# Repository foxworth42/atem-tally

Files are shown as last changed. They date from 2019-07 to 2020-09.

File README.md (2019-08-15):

# atem-tally
Yet another Arduino based ATEM tally light system.  This system is self-contained and talks to the ATEM directly.  The on camera lights are neo pixels driven over RS485 to allow for long cable runs.  The cabling between the cameras is done using ethernet cables for simplicity of wiring so we can send power + data to the remote lights.  The tally controller will also have a 20x4 LCD display for showing system status.  An XBee can also be added for supporting wireless remote tally lights.

# Still a work-in-progress

Everything here is still a work in process at the moment.  

Arduino code makes use of [Skaarhoj's Open Engineering arduino libraries](https://github.com/kasperskaarhoj/SKAARHOJ-Open-Engineering/tree/master/ArduinoLibs) for communicating with the Black Magic ATEM video switcher

Why roll something myself?  Cost, and it's an excuse to learn some C and do some PCB design.

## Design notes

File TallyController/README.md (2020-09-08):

Arduino based tally controller using the Arduino Mega w/ Ethernet.

Configuration of the tally controller is done via serial connection.  To configure send the following:

|Setting|Command|Note|
|---|---|---|
|Controller's IP|`Ix.x.x.x`|Replace x's with the controller's IP address|
|Controller's Netmask|`Nx.x.x.x`|Replace the x's with the controller's netmask|
|ATEM's IP|`Ax.x.x.x`|Replace the x's with the ATEM's IP address|
|Remote Camera #|`Rx`|Replace the x's with the camera # the wireless tally light is attached to|

Sample build of ATEM tally controller built in a parts organizer for portability for on-location use at conventions.

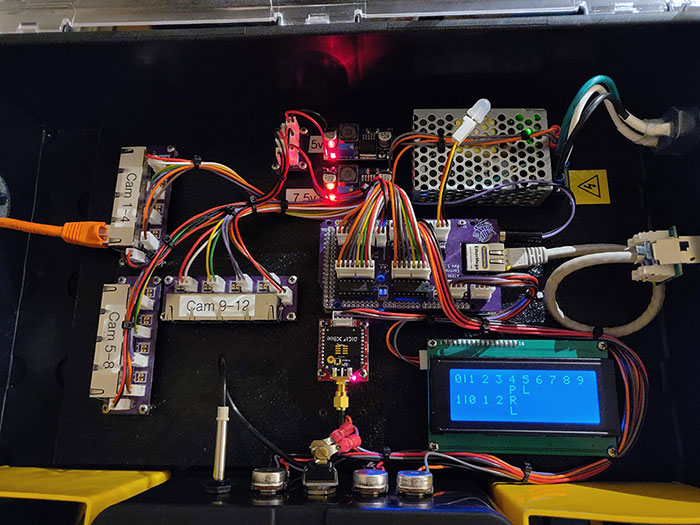
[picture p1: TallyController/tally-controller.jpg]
ATEM Tally Controller


# BOM:

## Controller Board:

For `tally-controller-shield-smd.brd`

|Component|Quantity|Notes|Link|
|---|---|---|---|
|Controller Shield PCB|1|Can have board fabbed anywhere.|[Link](https://oshpark.com/shared_projects/vglxha97)|
|Freetronics EtherMEGA|1|Arduino Mega + Ethernet bundle.  I do not recommend using the Mega ETH from RobotDyn.|[Link](https://www.freetronics.com.au/products/ethermega-arduino-mega-2560-compatible-with-onboard-ethernet)|
|SN75174N RS485 Quad Line Driver|3| |[Link](https://www.mouser.com/ProductDetail/595-SN75174N)|
|LM2596 DC/DC buck converters|2|I used 1 for the main 5v for the project, and the other just for powering the Ethermega|[Link](https://www.amazon.com/dp/B06XZ1DKF2/ref=cm_sw_em_r_mt_dp_U_vQXREb0CJX45Z)|
|Molex 22-23-2021 2-pin header|4| |[Link](https://www.mouser.com/ProductDetail/538-22-23-2021)|
|Molex 22-23-2031 3-pin header|3| |[Link](https://www.mouser.com/ProductDetail/538-22-23-2031)|
|Molex 22-23-2041 4-pin header|2| |[Link](https://www.mouser.com/ProductDetail/538-22-23-2041)|
|Molex 22-23-2081 8-pin header|3| |[Link](https://www.mouser.com/ProductDetail/538-22-23-2081)|
|470ohm 0805 SMD resistor|1| | |
|10kohm 0805 SMD resistor|1| | |
|4.7kohm 0805 SMD resistor|1| | |
|120ohm 0805 SMD resistor|12| | |
|0.1uf 0805 SMD ceramic capacitor|3| | |
|10kohm potentiometer|2| |[Link](https://www.mouser.com/ProductDetail/858-P231-QC15BR10K)|
|1kohm potentiometer|1| | |
|Potentiometer knob|3| |[Red](https://www.mouser.com/ProductDetail/450-3021), [Green](https://www.mouser.com/ProductDetail/450-3024), [Blue](https://www.mouser.com/ProductDetail/450-3023), [Yellow](https://www.mouser.com/ProductDetail/450-3022)
|SPST Toggle Swithch|1| | |
|Mean Well RS-25-12 Power Supply|1| |[Link](https://www.mouser.com/ProductDetail/709-RS25-12)|
|Sparkfun XBee regulated breakout|1|Optional|[Link](https://www.mouser.com/ProductDetail/474-WRL-11373)|
|XBee Pro Transciever|1|Optional|[Link](https://www.mouser.com/ProductDetail/888-XB3-24Z8ST)|
|Dome atenna for Xbee|1|Optional|[Link](https://www.mouser.com/ProductDetail/712-ANT-DB1-WRT-RPS)|
|20x4 LCD i2c Display|1|Can be had cheap off ebay| |

## Camera output board:

For `RJ45 4ch Outout.brd`

Quantities noted here are for each output board.  Multiply as needed for multiple boards.

|Component|Quantity|Notes|Link|
|---|---|---|---|
|Output PCB|1|Oshpark minimum order is 3|[Link](https://oshpark.com/shared_projects/SH81yZph)|
|Amphenol RJHSE-5380-04|1|4-port RJ45 module|[Link](https://www.mouser.com/ProductDetail/523-RJHSE-5380-04)|
|Molex 22-23-2021 2-pin header|4|Only needed for CAM#DATA1 headers.  CAM#DATA2 is unused currently.|[Link](https://www.mouser.com/ProductDetail/538-22-23-2021)|

## Power distribution

For `Output Power Distro.brd`

Small board for distributing the 5v power to the controller shield, camera output boards

|Component|Quantity|Notes|Link|
|---|---|---|---|
|Power Distro PCB|1|Oshpark minimum order is 3|[Link](https://oshpark.com/shared_projects/CbdMb8Fg)|
|Molex 22-23-2021 2-pin header|6|Only needed for CAM#DATA1 headers.  CAM#DATA2 is unused currently.|[Link](https://www.mouser.com/ProductDetail/538-22-23-2021)|

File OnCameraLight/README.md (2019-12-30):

RS485 receiver to Neopixel adapter for on-camera light.

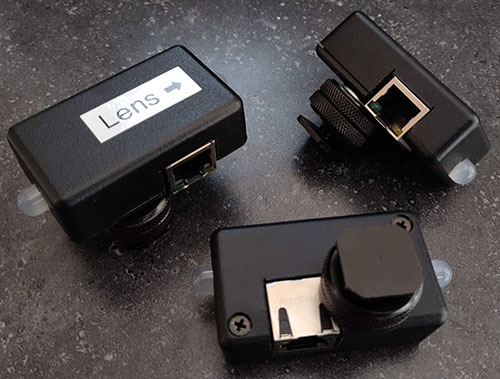
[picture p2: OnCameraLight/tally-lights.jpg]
On Camera Tally Light


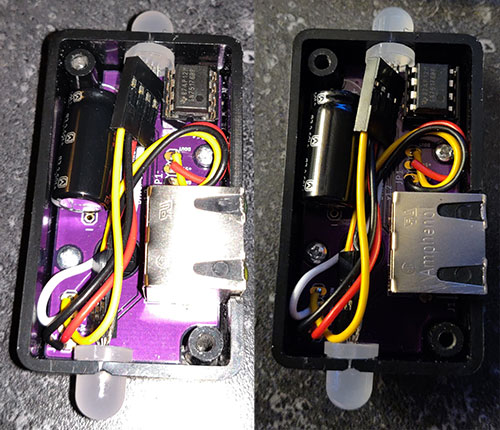
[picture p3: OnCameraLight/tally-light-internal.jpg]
On Camera Tally Light Internals


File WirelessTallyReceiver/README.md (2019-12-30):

XBee + Arduino Mini Pro based tally receiver.  Uses the same Neopixel LEDs as the wired lights, but wireless.

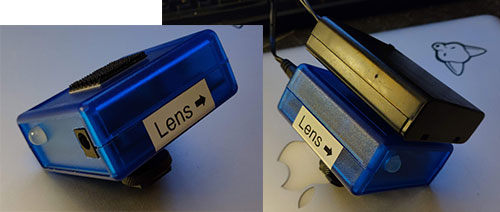
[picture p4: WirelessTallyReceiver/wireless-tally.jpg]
Wireless Tally Light


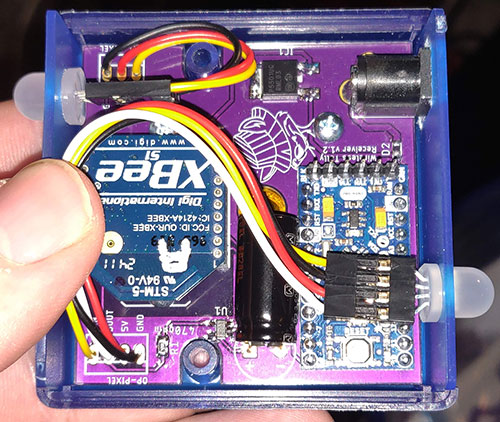
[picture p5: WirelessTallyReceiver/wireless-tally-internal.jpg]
Wireless Tally Light Internal


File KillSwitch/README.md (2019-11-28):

#Arduino based ATEM kill switch using Uno + Ethernet

This is for having an emergency kill switch for an ATEM that will dump
both the program and preview source to a pre-defined source if the button
is hit.  The reason it sets both program and preview is so that there 
needs to be manual intervention to bring the feed back online.

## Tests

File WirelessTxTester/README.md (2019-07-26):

Small sketch that can be used to test the wireless receiver, just cycles through the light options.

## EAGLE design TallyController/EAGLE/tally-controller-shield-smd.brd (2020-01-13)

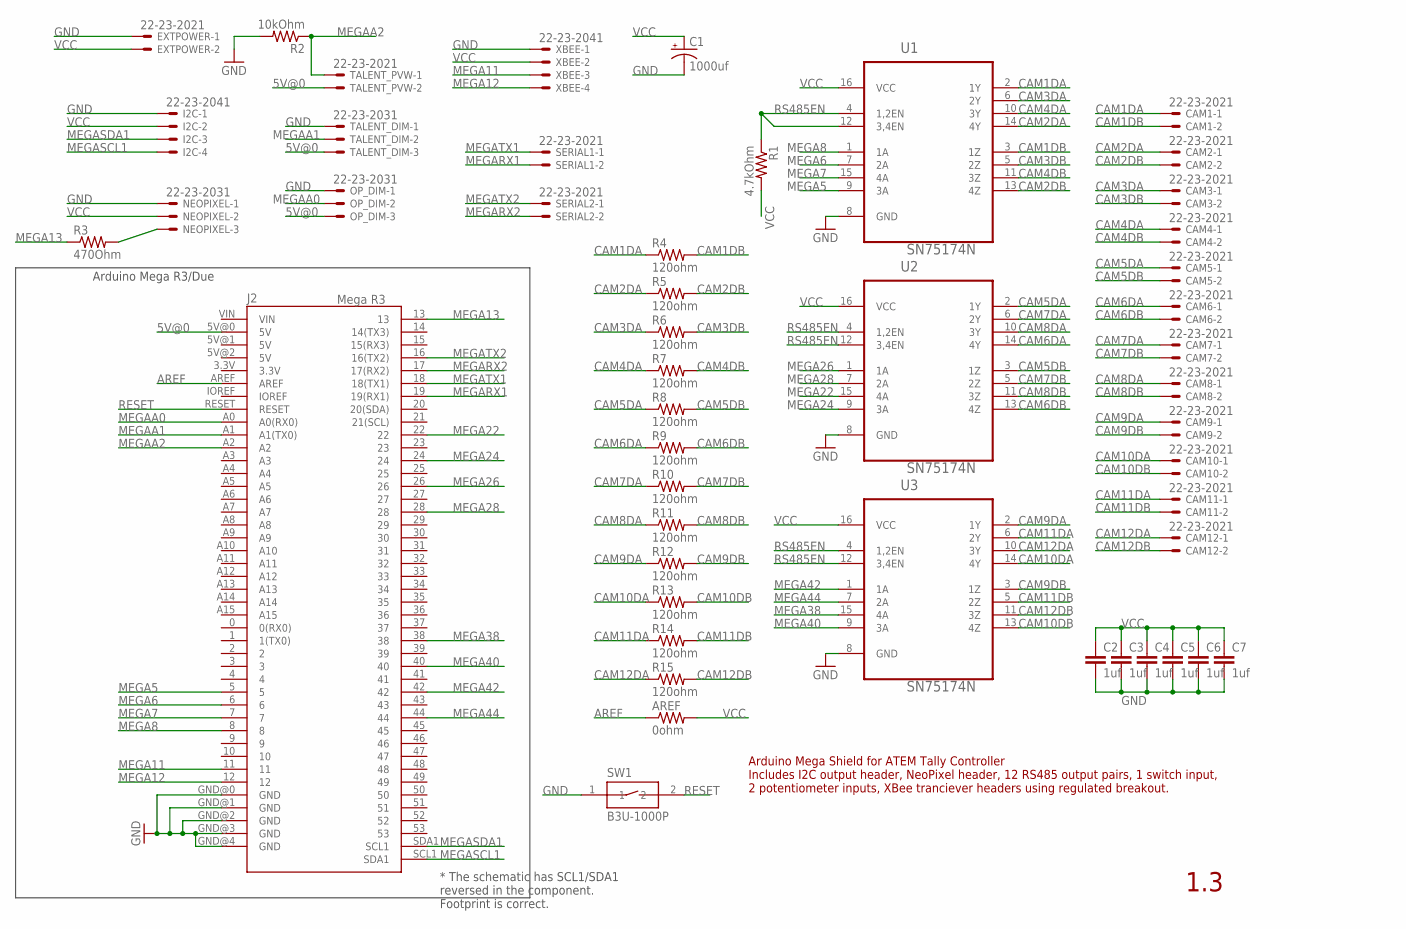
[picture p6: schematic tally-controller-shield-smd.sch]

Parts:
AREF: 0ohm; 0204V
C1: 1000uf; CPOL-RADIAL-5MM-10MM
C2, C3, C4, C5, C6, C7: 1uf; RESC0805_N
CAM1, CAM2, CAM3, CAM4, CAM5, CAM6, CAM7, CAM8, CAM9, CAM10, CAM11, CAM12: 22-23-2021
EXTPOWER: 22-23-2021
I2C: 22-23-2041
J2: Mega R3; ARDUINO_MEGA
NEOPIXEL: 22-23-2031
OP_DIM: 22-23-2031
R1: 4.7kOhm; R0805
R2: 10kOhm; R0805
R3: 470Ohm; R0805
R4, R5, R6, R7, R8, R9, R10, R11, R12, R13, R14, R15: 120ohm; R0805
SERIAL1, SERIAL2: 22-23-2021
SW1: B3U-1000P
TALENT_DIM: 22-23-2031
TALENT_PVW: 22-23-2021
U1, U2, U3: SN75174N; DIP254P762X508-16
XBEE: 22-23-2041

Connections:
5V@0: J2.5V@0 (5V), OP_DIM.3, TALENT_DIM.3, TALENT_PVW.2
AREF: AREF.1, J2.AREF
CAM1DA: CAM1.1, R4.1, U1.2 (1Y)
CAM1DB: CAM1.2, R4.2, U1.3 (1Z)
CAM2DA: CAM2.1, R5.1, U1.14 (4Y)
CAM2DB: CAM2.2, R5.2, U1.13 (4Z)
CAM3DA: CAM3.1, R6.1, U1.6 (2Y)
CAM3DB: CAM3.2, R6.2, U1.5 (2Z)
CAM4DA: CAM4.1, R7.1, U1.10 (3Y)
CAM4DB: CAM4.2, R7.2, U1.11 (3Z)
CAM5DA: CAM5.1, R8.1, U2.2 (1Y)
CAM5DB: CAM5.2, R8.2, U2.3 (1Z)
CAM6DA: CAM6.1, R9.1, U2.14 (4Y)
CAM6DB: CAM6.2, R9.2, U2.13 (4Z)
CAM7DA: CAM7.1, R10.1, U2.6 (2Y)
CAM7DB: CAM7.2, R10.2, U2.5 (2Z)
CAM8DA: CAM8.1, R11.1, U2.10 (3Y)
CAM8DB: CAM8.2, R11.2, U2.11 (3Z)
CAM9DA: CAM9.1, R12.1, U3.2 (1Y)
CAM9DB: CAM9.2, R12.2, U3.3 (1Z)
CAM10DA: CAM10.1, R13.1, U3.14 (4Y)
CAM10DB: CAM10.2, R13.2, U3.13 (4Z)
CAM11DA: CAM11.1, R14.1, U3.6 (2Y)
CAM11DB: CAM11.2, R14.2, U3.5 (2Z)
CAM12DA: CAM12.1, R15.1, U3.10 (3Y)
CAM12DB: CAM12.2, R15.2, U3.11 (3Z)
GND: C1.-, C2.2, C3.2, C4.2, C5.2, C6.2, C7.2, EXTPOWER.1, I2C.1, J2.GND@0 (GND), J2.GND@1 (GND), J2.GND@2 (GND), J2.GND@3 (GND), J2.GND@4 (GND), NEOPIXEL.1, OP_DIM.1, R2.2, SW1.1, TALENT_DIM.1, U1.8 (GND), U2.8 (GND), U3.8 (GND), XBEE.1
MEGA5: J2.5, U1.9 (3A)
MEGA6: J2.6, U1.7 (2A)
MEGA7: J2.7, U1.15 (4A)
MEGA8: J2.8, U1.1 (1A)
MEGA11: J2.11, XBEE.3
MEGA12: J2.12, XBEE.4
MEGA13: J2.13, R3.1
MEGA22: J2.22, U2.15 (4A)
MEGA24: J2.24, U2.9 (3A)
MEGA26: J2.26, U2.1 (1A)
MEGA28: J2.28, U2.7 (2A)
MEGA38: J2.38, U3.15 (4A)
MEGA40: J2.40, U3.9 (3A)
MEGA42: J2.42, U3.1 (1A)
MEGA44: J2.44, U3.7 (2A)
MEGAA0: J2.A0 (A0(RX0)), OP_DIM.2
MEGAA1: J2.A1 (A1(TX0)), TALENT_DIM.2
MEGAA2: J2.A2, R2.1, TALENT_PVW.1
MEGARX1: J2.19 (19(RX1)), SERIAL1.2
MEGARX2: J2.17 (17(RX2)), SERIAL2.2
MEGASCL1: I2C.4, J2.SCL1 (SDA1)
MEGASDA1: I2C.3, J2.SDA1 (SCL1)
MEGATX1: J2.18 (18(TX1)), SERIAL1.1
MEGATX2: J2.16 (16(TX2)), SERIAL2.1
NEOPIXELDATA: NEOPIXEL.3, R3.2
RESET: J2.RESET, SW1.2
RS485EN: R1.1, U1.4 (1,2EN), U1.12 (3,4EN), U2.4 (1,2EN), U2.12 (3,4EN), U3.4 (1,2EN), U3.12 (3,4EN)
VCC: AREF.2, C1.+, C2.1, C3.1, C4.1, C5.1, C6.1, C7.1, EXTPOWER.2, I2C.2, NEOPIXEL.2, R1.2, U1.16 (VCC), U2.16 (VCC), U3.16 (VCC), XBEE.2

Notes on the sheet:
Arduino Mega R3/Due
Arduino Mega Shield for ATEM Tally Controller Includes I2C output header, NeoPixel header, 12 RS485 output pairs, 1 switch input, 2 potentiometer inputs, XBee tranciever headers using regulated breakout.
1.3
* The schematic has SCL1/SDA1 reversed in the component. Footprint is correct.

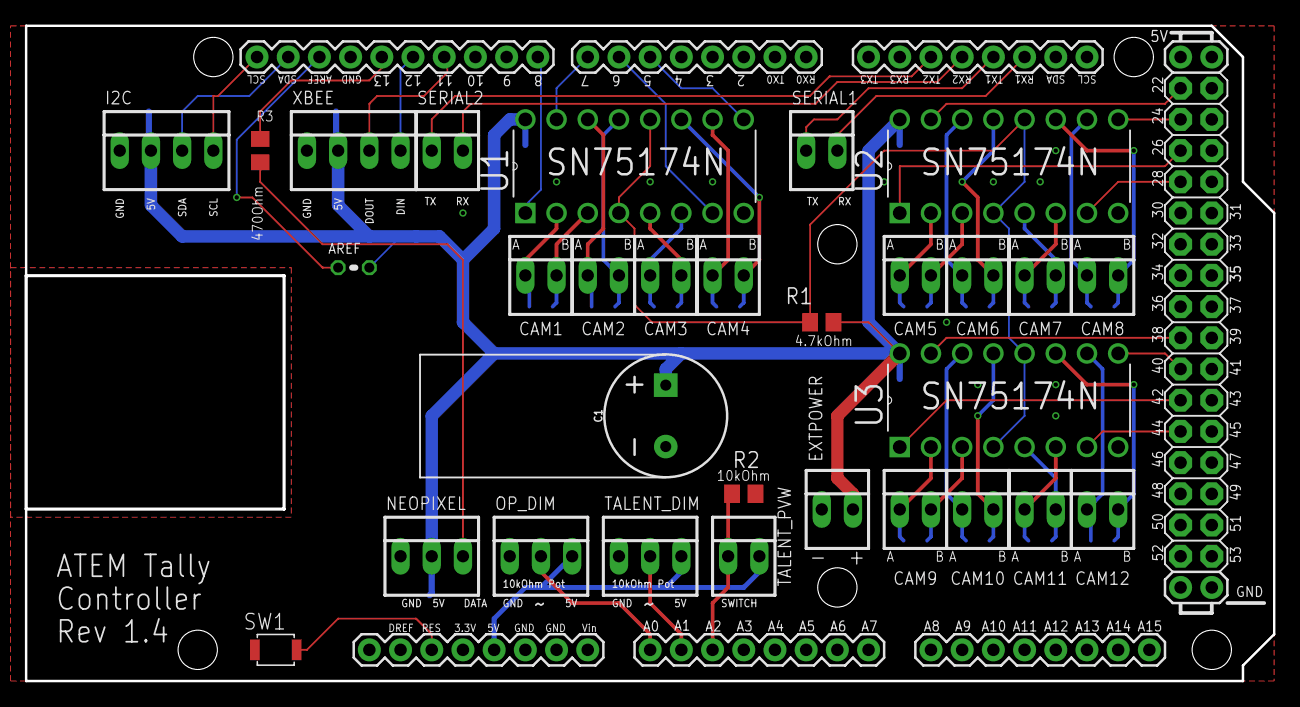
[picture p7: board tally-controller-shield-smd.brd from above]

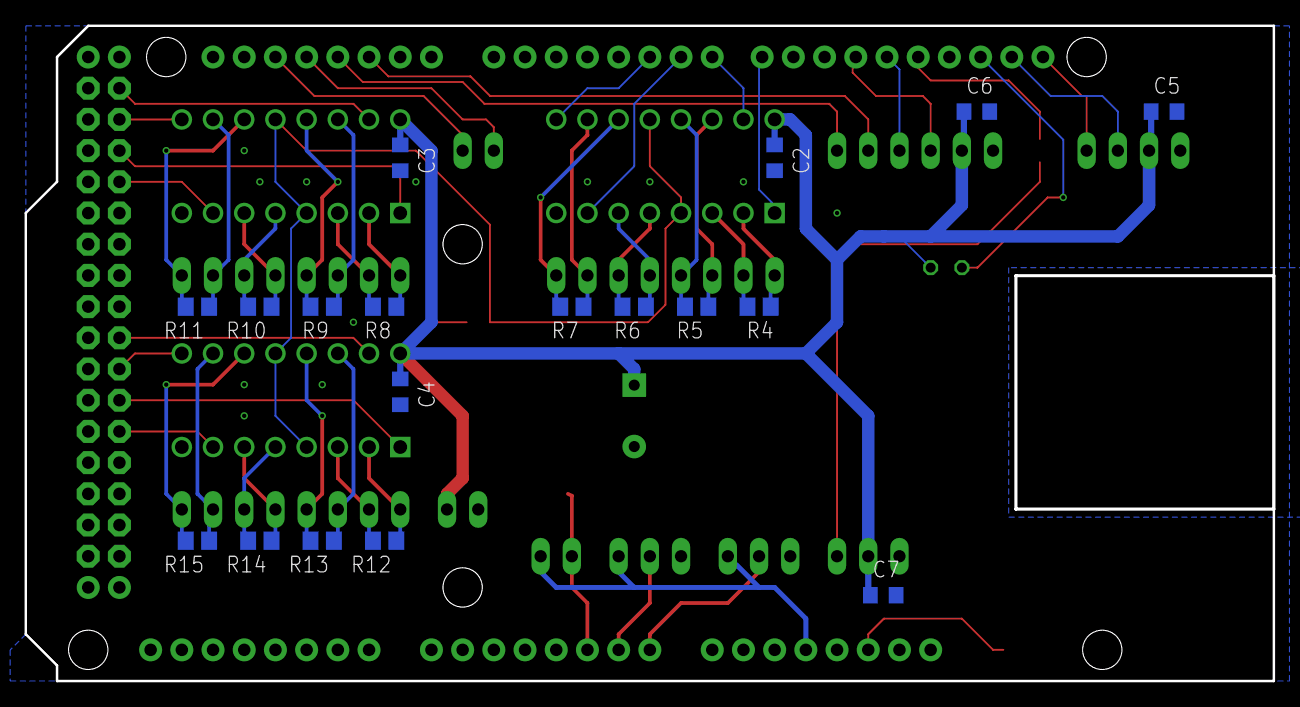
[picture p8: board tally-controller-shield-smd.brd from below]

Board: 2 copper layers, 101.6 x 53.3 mm, 49 parts (18 on the bottom side), 55 nets.

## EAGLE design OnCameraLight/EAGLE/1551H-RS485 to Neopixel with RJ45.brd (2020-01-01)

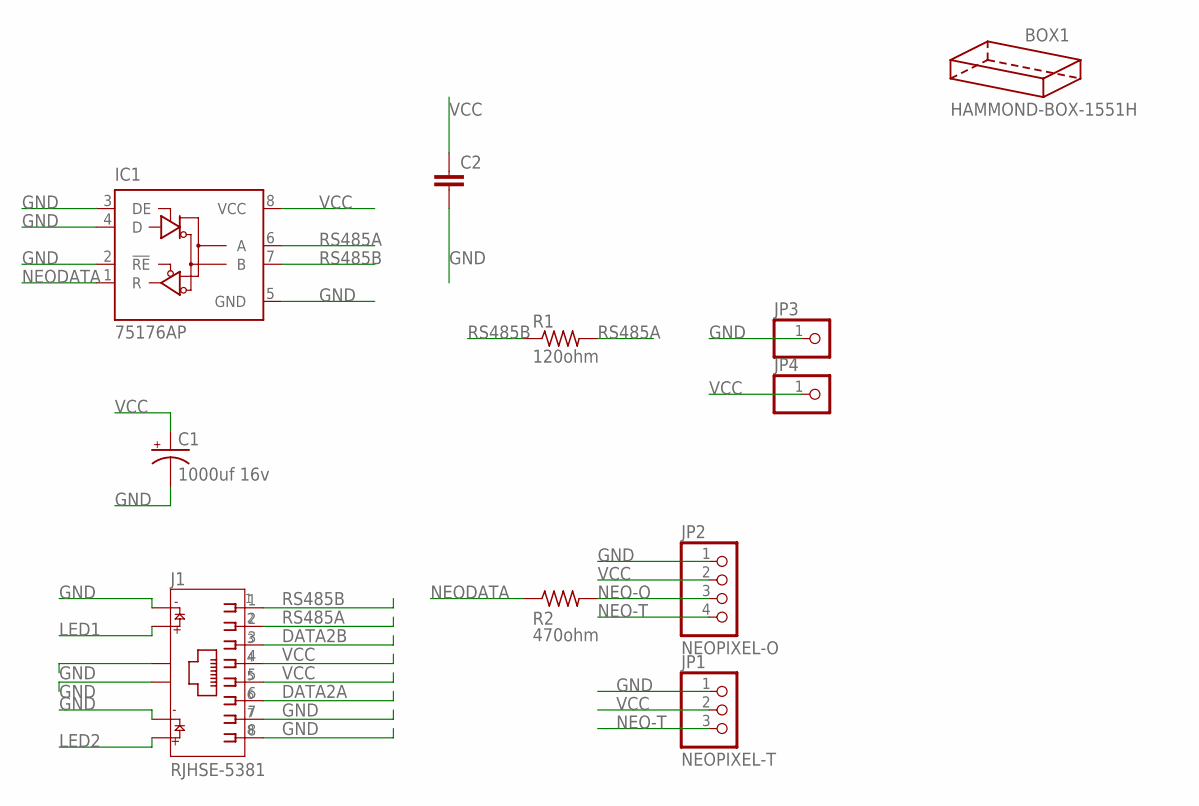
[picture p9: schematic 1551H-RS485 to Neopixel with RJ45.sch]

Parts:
BOX1: HAMMOND-BOX-1551H; 1551H
C1: 1000uf 16v; CPOL-RADIAL-5MM-10MM
C2: CAPACITOR_0805_N; RESC0805_N
IC1: 75176AP; DIL08
J1: RJHSE-5381; AMPHENOL_RJHSE-5381
JP1: NEOPIXEL-T; 1X03
JP2: NEOPIXEL-O; 1X04
JP3, JP4: PINHD-1X1; 1X01
R1: 120ohm; R0805
R2: 470ohm; R0805

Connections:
DATA2A: J1.6
DATA2B: J1.3
GND: C1.-, C2.2, IC1.2 (!RE), IC1.3 (DE), IC1.4 (D), IC1.5 (GND), J1.7, J1.8, J1.9, J1.11, J1.S1, J1.S2, JP1.1, JP2.1, JP3.1
LED1: J1.10
LED2: J1.12
NEO-O: JP2.3, R2.2
NEO-T: JP1.3, JP2.4
NEODATA: IC1.1 (R), R2.1
RS485A: IC1.6 (A), J1.2, R1.2
RS485B: IC1.7 (B), J1.1, R1.1
VCC: C1.+, C2.1, IC1.8 (VCC), J1.4, J1.5, JP1.2, JP2.2, JP4.1

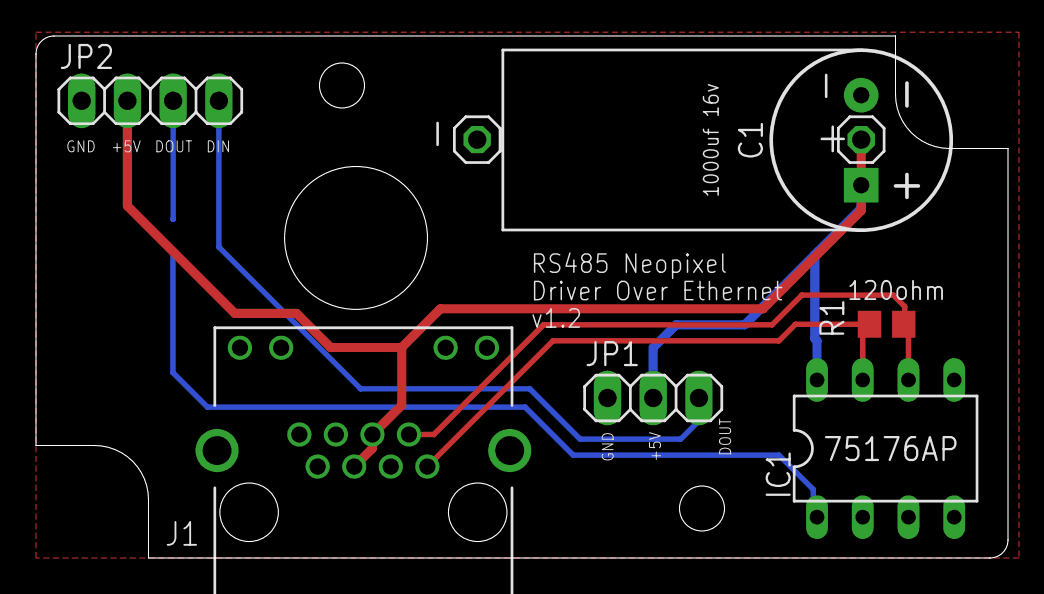
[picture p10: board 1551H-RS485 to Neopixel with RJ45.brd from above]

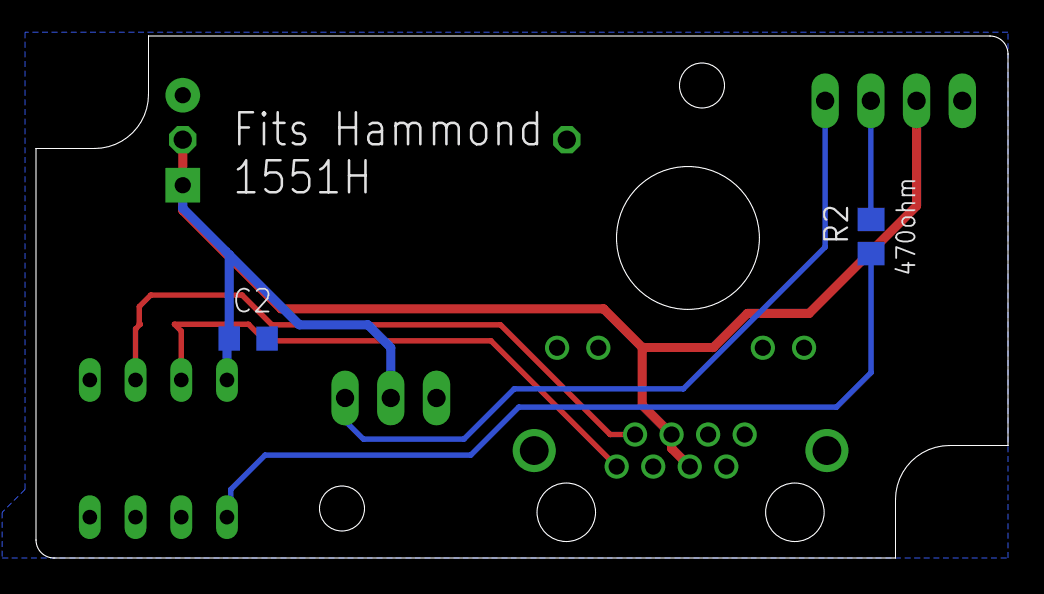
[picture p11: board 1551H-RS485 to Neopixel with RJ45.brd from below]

Board: 2 copper layers, 54.0 x 29.0 mm, 11 parts (2 on the bottom side), 7 nets.

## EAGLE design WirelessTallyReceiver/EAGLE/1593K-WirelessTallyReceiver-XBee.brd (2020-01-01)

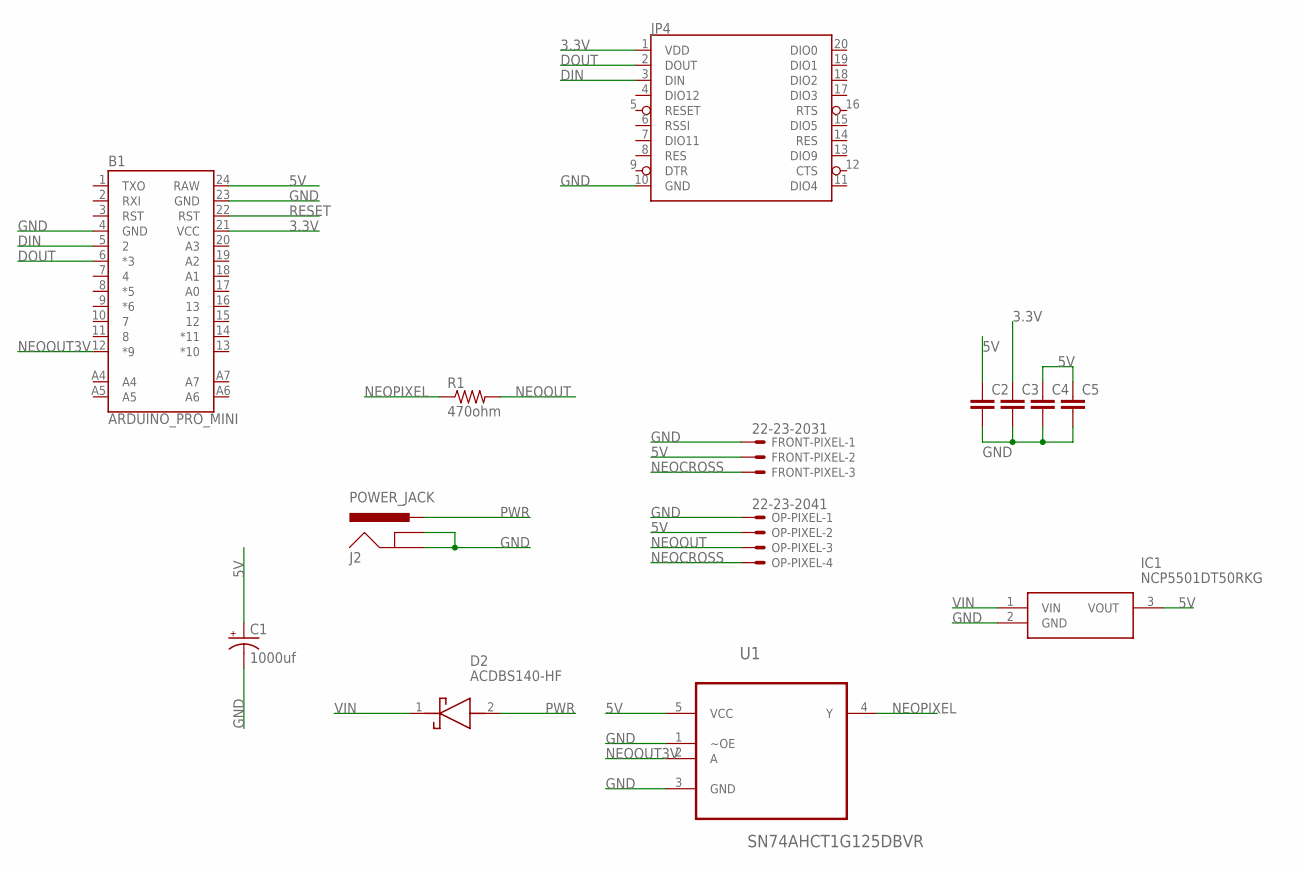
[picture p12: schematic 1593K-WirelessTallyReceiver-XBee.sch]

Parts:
B1: ARDUINO_PRO_MINI
C1: 1000uf; CPOL-RADIAL-5MM-10MM
C2, C3, C4, C5: CAPACITOR_0805_N; RESC0805_N
D2: ACDBS140-HF; DIOM2013X100N
FRONT-PIXEL: 22-23-2031
IC1: NCP5501DT50RKG
J2: POWER_JACK; POWER_JACK_PTH
JP4: XBEESILK; XBEE-SILK
OP-PIXEL: 22-23-2041
R1: 470ohm; R0805
U1: SN74AHCT1G125DBVR; SOT95P280X145-5N

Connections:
3.3V: B1.21 (VCC), C3.1, JP4.1 (VDD)
5V: B1.24 (RAW), C1.+, C2.1, C4.1, C5.1, FRONT-PIXEL.2, IC1.3 (VOUT), OP-PIXEL.2, U1.5 (VCC)
DIN: B1.5 (2), JP4.3 (DIN)
DOUT: B1.6 (*3), JP4.2 (DOUT)
GND: B1.4 (GND), B1.23 (GND), C1.-, C2.2, C3.2, C4.2, C5.2, FRONT-PIXEL.1, IC1.2 (GND), J2.GND, J2.GNDBREAK, JP4.10 (GND), OP-PIXEL.1, U1.1 (~OE), U1.3 (GND)
NEOCROSS: FRONT-PIXEL.3, OP-PIXEL.4
NEOOUT: OP-PIXEL.3, R1.2
NEOOUT3V: B1.12 (*9), U1.2 (A)
NEOPIXEL: R1.1, U1.4 (Y)
PWR: D2.2 (A), J2.PWR
RESET: B1.22 (RST)
VIN: D2.1 (K), IC1.1 (VIN)

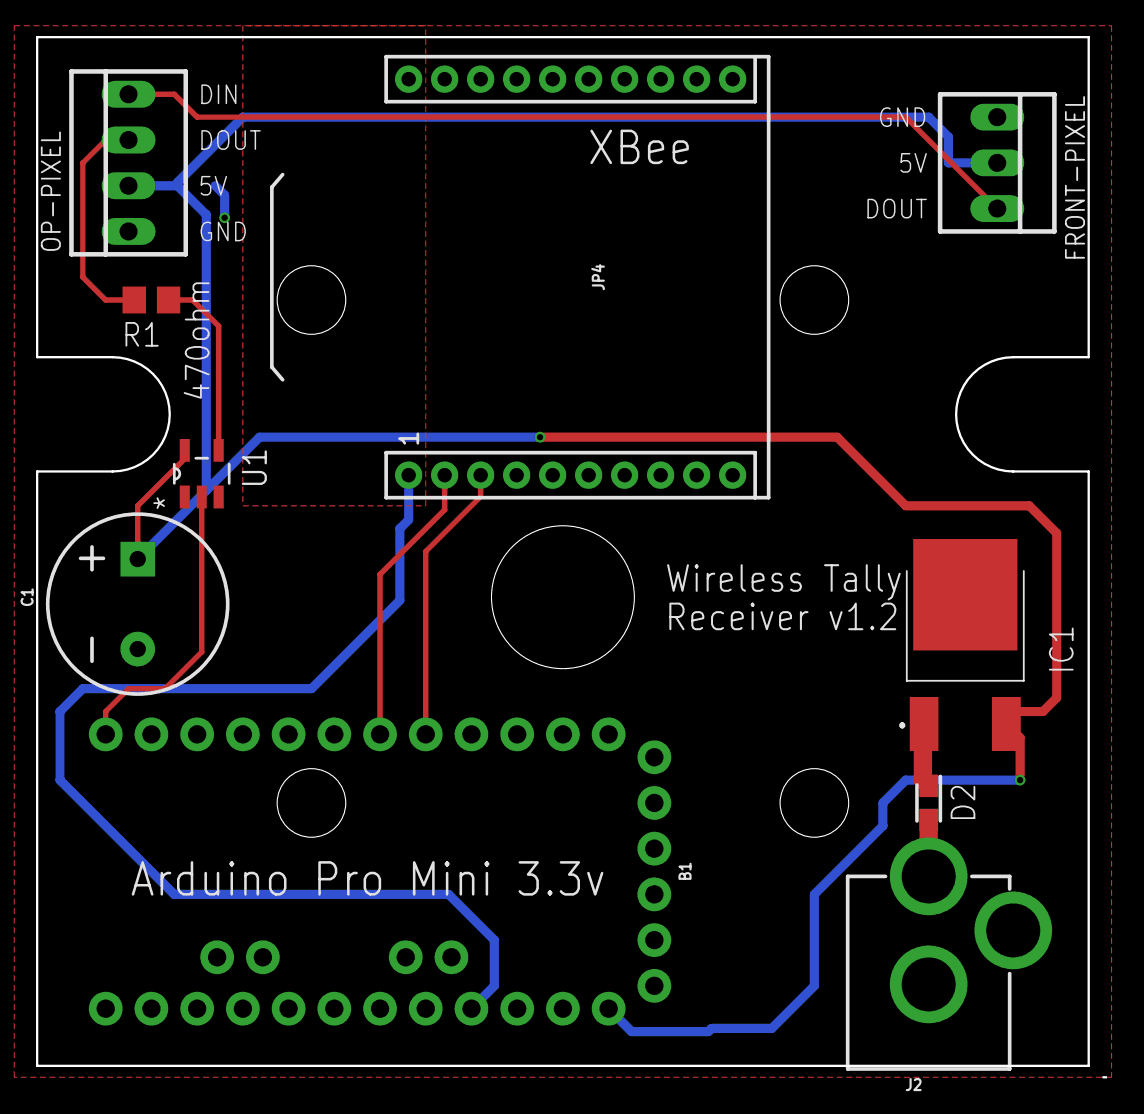
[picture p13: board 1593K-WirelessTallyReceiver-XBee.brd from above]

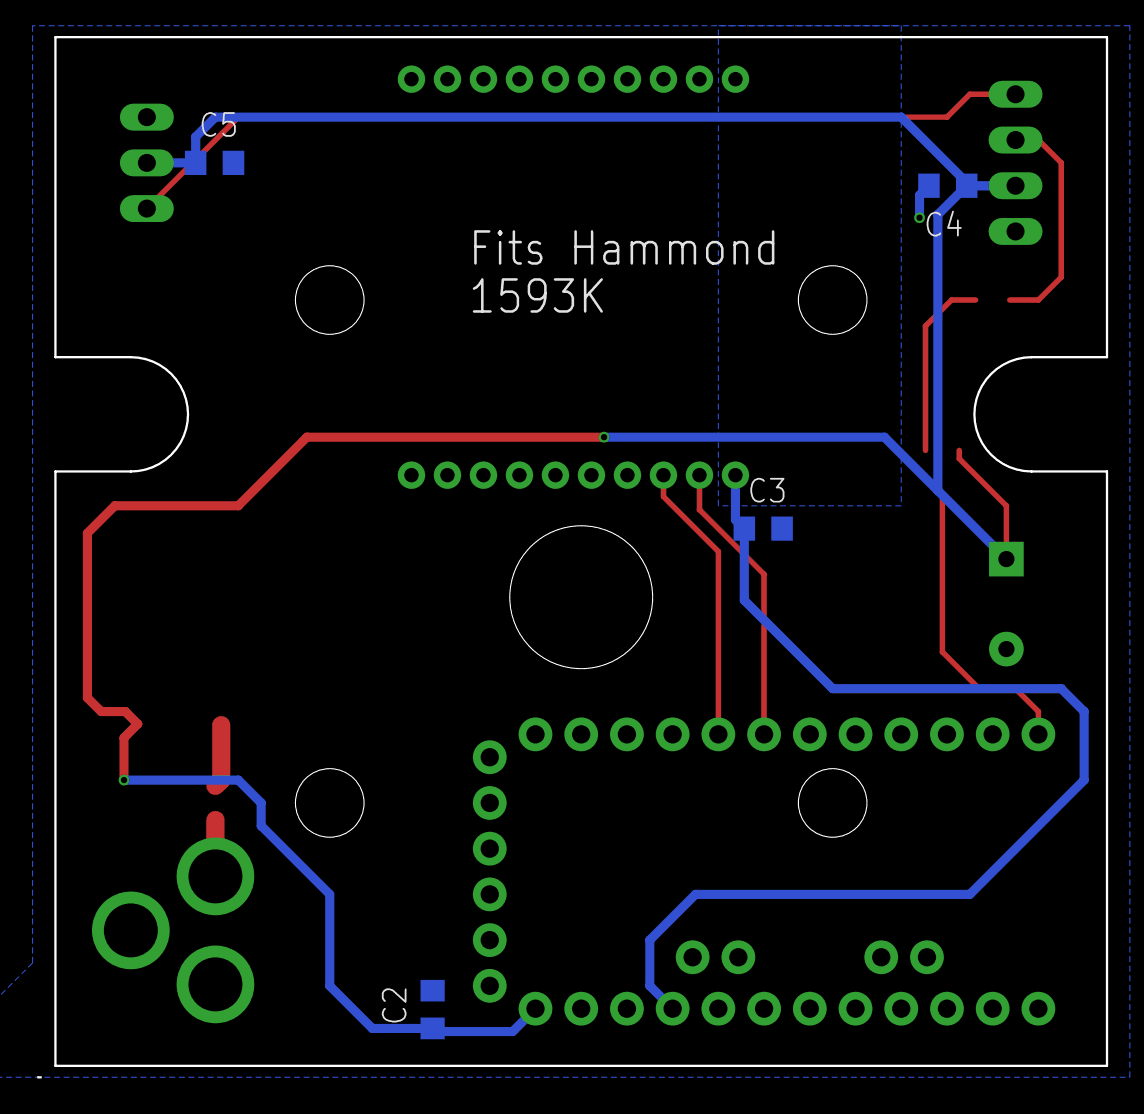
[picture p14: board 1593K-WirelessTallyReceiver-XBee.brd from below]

Board: 2 copper layers, 59.4 x 57.8 mm, 15 parts (4 on the bottom side), 11 nets.

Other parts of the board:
U$1: 1593K

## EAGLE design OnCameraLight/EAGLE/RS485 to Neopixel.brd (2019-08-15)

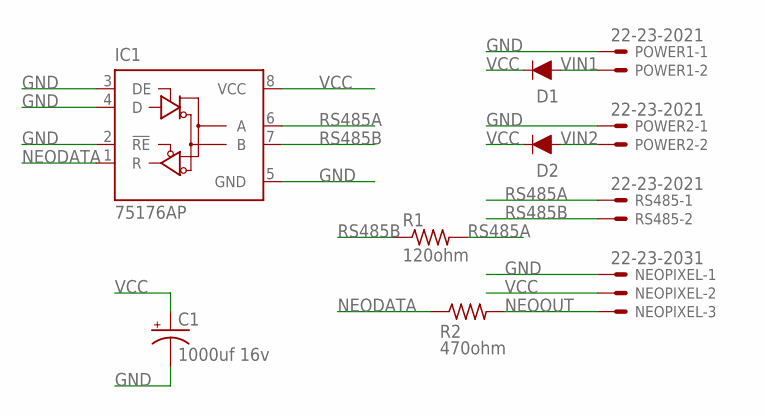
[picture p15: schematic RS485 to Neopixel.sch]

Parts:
C1: 1000uf 16v; CPOL-RADIAL-5MM-10MM
D1, D2: 1A/50V/1.1V; DIODE-1N4001
IC1: 75176AP; DIL08
NEOPIXEL: 22-23-2031
POWER1, POWER2: 22-23-2021
R1: 120ohm; 0207/10
R2: 470ohm; 0207/10
RS485: 22-23-2021

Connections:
GND: C1.-, IC1.2 (!RE), IC1.3 (DE), IC1.4 (D), IC1.5 (GND), NEOPIXEL.1, POWER1.1, POWER2.1
NEODATA: IC1.1 (R), R2.1
NEOOUT: NEOPIXEL.3, R2.2
RS485A: IC1.6 (A), R1.2, RS485.1
RS485B: IC1.7 (B), R1.1, RS485.2
VCC: C1.+, D1.C, D2.C, IC1.8 (VCC), NEOPIXEL.2
VIN1: D1.A, POWER1.2
VIN2: D2.A, POWER2.2

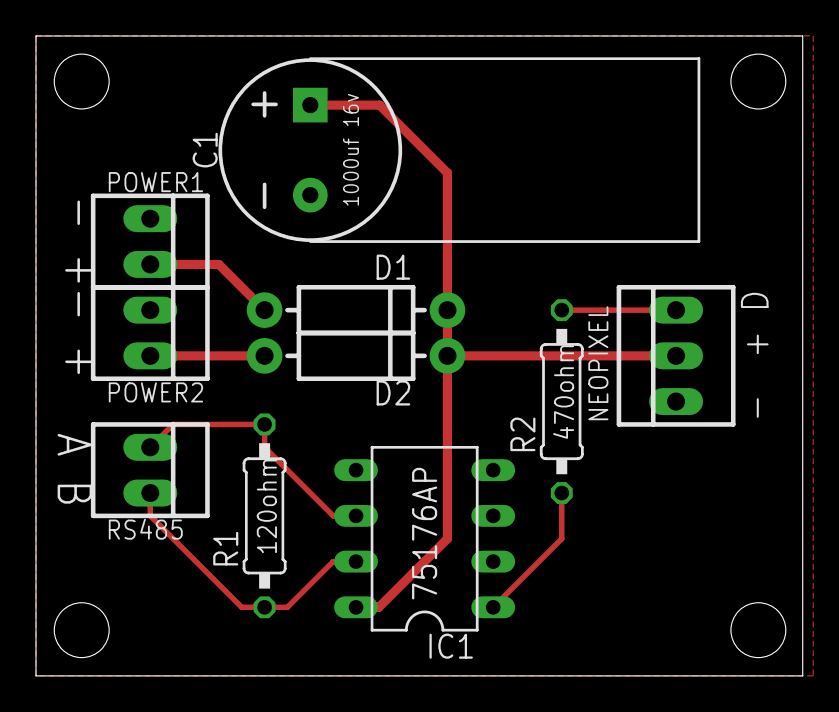
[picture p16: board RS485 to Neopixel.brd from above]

Board: 2 copper layers, 42.6 x 35.5 mm, 10 parts (0 on the bottom side), 8 nets.

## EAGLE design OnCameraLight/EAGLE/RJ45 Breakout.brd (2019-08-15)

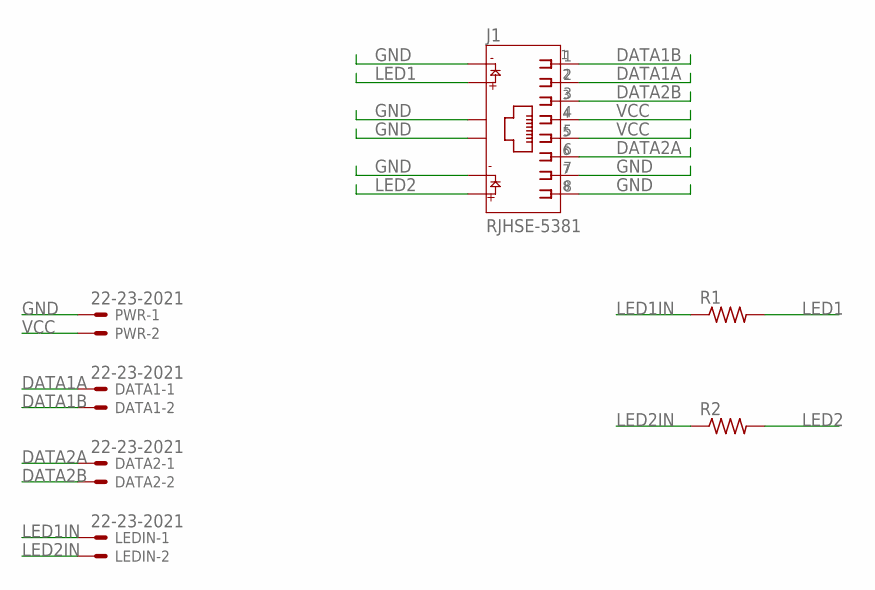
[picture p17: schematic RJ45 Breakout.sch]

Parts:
DATA1, DATA2: 22-23-2021
J1: RJHSE-5381; AMPHENOL_RJHSE-5381
LEDIN: 22-23-2021
PWR: 22-23-2021
R1, R2: R-US_0207/10; 0207/10

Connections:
DATA1A: DATA1.1, J1.2
DATA1B: DATA1.2, J1.1
DATA2A: DATA2.1, J1.6
DATA2B: DATA2.2, J1.3
GND: J1.7, J1.8, J1.9, J1.11, J1.S1, J1.S2, PWR.1
LED1: J1.10, R1.2
LED1IN: LEDIN.1, R1.1
LED2: J1.12, R2.2
LED2IN: LEDIN.2, R2.1
VCC: J1.4, J1.5, PWR.2


Board: 2 copper layers, 28.6 x 35.5 mm, 7 parts (0 on the bottom side), 10 nets.

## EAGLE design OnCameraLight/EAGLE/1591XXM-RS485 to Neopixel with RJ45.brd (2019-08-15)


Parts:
C1: 1000uf 16v; CPOL-RADIAL-5MM-10MM
D1, D2: 1A/50V/1.1V; DIODE-1N4001
DATA2: 22-23-2021
IC1: 75176AP; DIL08
J1: RJHSE-5381; AMPHENOL_RJHSE-5381
LEDIN: 22-23-2021
NEOPIXEL-O: 22-23-2041
NEOPIXEL-T: 22-23-2031
POWER2: 22-23-2021
POWEROUT: 22-23-2021
R1: 120ohm; 0207/10
R2: 470ohm; 0207/10
R3, R4: R-US_0207/10; 0207/10

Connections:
DATA1A: IC1.6 (A), J1.2, R1.1
DATA1B: IC1.7 (B), J1.1, R1.2
DATA2A: DATA2.1, J1.6
DATA2B: DATA2.2, J1.3
GND: C1.-, IC1.2 (!RE), IC1.3 (DE), IC1.4 (D), IC1.5 (GND), J1.7, J1.8, J1.9, J1.11, J1.S1, J1.S2, NEOPIXEL-O.1, NEOPIXEL-T.1, POWER2.1, POWEROUT.1
LED1: J1.10, R3.2
LED1IN: LEDIN.1, R3.1
LED2: J1.12, R4.2
LED2IN: LEDIN.2, R4.1
NEO-O: NEOPIXEL-O.3, R2.2
NEO-T: NEOPIXEL-O.4, NEOPIXEL-T.3
NEODATA: IC1.1 (R), R2.1
VCC: C1.+, D1.C, D2.C, IC1.8 (VCC), NEOPIXEL-O.2, NEOPIXEL-T.2, POWEROUT.2
VIN1: D1.A, J1.4, J1.5
VIN2: D2.A, POWER2.2


Board: 2 copper layers, 80.7 x 51.5 mm, 16 parts (0 on the bottom side), 15 nets.

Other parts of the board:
U$1: 1591XXM

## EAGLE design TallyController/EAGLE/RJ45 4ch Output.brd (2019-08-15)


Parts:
CAM1DATA1, CAM1DATA2, CAM2DATA1, CAM2DATA2, CAM3DATA1, CAM3DATA2, CAM4DATA1, CAM4DATA2: 22-23-2021
J1: RJHSE-5381-04; AMPHENOL_RJHSE-5381-04
POWER: 22-23-2021

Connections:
C1DATA1A: CAM1DATA1.1, J1.2
C1DATA1B: CAM1DATA1.2, J1.1
C1DATA2A: CAM1DATA2.1, J1.6
C1DATA2B: CAM1DATA2.2, J1.3
C2DATA1A: CAM2DATA1.1, J1.14
C2DATA1B: CAM2DATA1.2, J1.13
C2DATA2A: CAM2DATA2.1, J1.18
C2DATA2B: CAM2DATA2.2, J1.15
C3DATA1A: CAM3DATA1.1, J1.26
C3DATA1B: CAM3DATA1.2, J1.25
C3DATA2A: CAM3DATA2.1, J1.30
C3DATA2B: CAM3DATA2.2, J1.27
C4DATA1A: CAM4DATA1.1, J1.38
C4DATA1B: CAM4DATA1.2, J1.37
C4DATA2A: CAM4DATA2.1, J1.42
C4DATA2B: CAM4DATA2.2, J1.39
GND: J1.7, J1.8, J1.9, J1.11, J1.19, J1.20, J1.21, J1.23, J1.31, J1.32, J1.33, J1.35, J1.43, J1.44, J1.45, J1.47, J1.S1 (SHIELD), J1.S2 (SHIELD), J1.S3 (SHIELD), J1.S4 (SHIELD), POWER.1
LED1A: J1.10
LED1B: J1.12
LED2A: J1.22
LED2B: J1.24
LED3A: J1.34
LED3B: J1.36
LED4A: J1.46
LED4B: J1.48
VCC: J1.4, J1.5, J1.16, J1.17, J1.28, J1.29, J1.40, J1.41, POWER.2


Board: 2 copper layers, 80.3 x 26.7 mm, 10 parts (0 on the bottom side), 18 nets.

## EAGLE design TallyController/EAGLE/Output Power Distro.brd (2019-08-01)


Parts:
IN: 22-23-2021
OUT1, OUT2, OUT3, OUT4, OUT5: 22-23-2021

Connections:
GND: IN.1, OUT1.1, OUT2.1, OUT3.1, OUT4.1, OUT5.1
VCC: IN.2, OUT1.2, OUT2.2, OUT3.2, OUT4.2, OUT5.2

Board: 2 copper layers, 6 parts (0 on the bottom side), 2 nets, no tracks yet.

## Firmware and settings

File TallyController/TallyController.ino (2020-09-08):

#include "TallyController.h"

// 8mm/5mm Neopixels use NEO_RGB, adjust accordingly if you use something else
Adafruit_NeoPixel tallyUnit[12] = {
  Adafruit_NeoPixel(LED_COUNT, CAM1, NEO_RGB + NEO_KHZ800),
  Adafruit_NeoPixel(LED_COUNT, CAM2, NEO_RGB + NEO_KHZ800),
  Adafruit_NeoPixel(LED_COUNT, CAM3, NEO_RGB + NEO_KHZ800),
  Adafruit_NeoPixel(LED_COUNT, CAM4, NEO_RGB + NEO_KHZ800),
  Adafruit_NeoPixel(LED_COUNT, CAM5, NEO_RGB + NEO_KHZ800),
  Adafruit_NeoPixel(LED_COUNT, CAM6, NEO_RGB + NEO_KHZ800),
  Adafruit_NeoPixel(LED_COUNT, CAM7, NEO_RGB + NEO_KHZ800),
  Adafruit_NeoPixel(LED_COUNT, CAM8, NEO_RGB + NEO_KHZ800),
  Adafruit_NeoPixel(LED_COUNT, CAM9, NEO_RGB + NEO_KHZ800),
  Adafruit_NeoPixel(LED_COUNT, CAM10, NEO_RGB + NEO_KHZ800),
  Adafruit_NeoPixel(LED_COUNT, CAM11, NEO_RGB + NEO_KHZ800),
  Adafruit_NeoPixel(LED_COUNT, CAM12, NEO_RGB + NEO_KHZ800)
};

Adafruit_NeoPixel statusLed(1, STATUS_NEOPIXEL, NEO_RGB + NEO_KHZ800);
LiquidCrystal_I2C lcd(0x27,20,4);
SoftwareSerial XBee(XBEE_In, XBEE_Out);  // TX, RX
ATEMmin AtemSwitcher;

void(* reboot) (void) = 0;

void setup() {
  pinMode(4,OUTPUT);
  digitalWrite(4,HIGH);
  pinMode(10,OUTPUT);
  digitalWrite(10,HIGH);
  pinMode(53,OUTPUT);

  randomSeed(analogRead(5));

  XBee.begin(9600);
  // Open serial communications and wait for port to open:
  Serial.begin(9600);
  while (!Serial) {
    ; // wait for serial port to connect. Needed for native USB port only
  }

  doInit();
}

void doInit() {
  
  lcd.init();
  lcd.backlight();
  lcd.clear();

  for (uint8_t i = 0; i < numberOfTallyLights; i++) {
    tallyUnit[i].begin();
    tallyUnit[i].setBrightness(50);
    tallyUnit[i].clear();
    tallyUnit[i].show();
  }

  statusLed.begin();
  statusLed.setBrightness(128);
  statusLed.clear();
  statusLed.show();

  XBee.write("L");
  setAll(tallyUnit[0].Color(128,0,0));

  IPAddress ip(EEPROM.read(0), EEPROM.read(1), EEPROM.read(2), EEPROM.read(3));
  IPAddress netmask(EEPROM.read(4), EEPROM.read(5), EEPROM.read(6), EEPROM.read(7));
  IPAddress switcherIp(EEPROM.read(8), EEPROM.read(9), EEPROM.read(10), EEPROM.read(11));
  remoteCameraNumber = EEPROM.read(12);
  
  Serial.println("Initialize Ethernet:");
  lcd.print("Init Ethernet");
  Ethernet.init(10);  // Most Arduino shields
  Ethernet.begin(mac, ip);
  Ethernet.setSubnetMask(netmask);


  if (Ethernet.hardwareStatus() == EthernetNoHardware) {
    lcd.setCursor(0,0);
    lcd.print("Ethernet shield");
    lcd.setCursor(0,1);
    lcd.print("was not found.");
    Serial.println("Ethernet shield was not found.");
    while (true) {
      delay(1);
    }
  } else if (Ethernet.linkStatus() == LinkOFF) {
    lcd.setCursor(0,2);
    lcd.print("Ethernet cable is not connected.");
    Serial.println("Ethernet cable is not connected.");
    while (true) {
      delay(1);
    }
  }
 
  XBee.write("T");
  setAll(tallyUnit[0].Color(0,128,0));
  
  // print local IP address:
  Serial.print("My IP address: ");
  Serial.println(Ethernet.localIP());
  Serial.print("Subnet Mask: ");
  Serial.println(Ethernet.subnetMask());
  lcd.clear();
  lcd.setCursor(0,0);
  lcd.print("IP Address:");
  lcd.setCursor(0,1);
  lcd.print(Ethernet.localIP());
  lcd.setCursor(0,2);
  lcd.print("Subnet Mask: ");
  lcd.setCursor(0,3);
  lcd.print(Ethernet.subnetMask());

  AtemSwitcher.begin(switcherIp);
  AtemSwitcher.serialOutput(1);
  AtemSwitcher.connect();

  XBee.write("B");
  setAll(tallyUnit[0].Color(0,0,128));

  delay(2000);

  lcd.clear();
  lcd.setCursor(0,0);
  lcd.print("ATEM IP Address:");
  lcd.setCursor(0,1);
  lcd.print(switcherIp);
  lcd.setCursor(0,2);
  lcd.print("Remote Camera #:");
  lcd.setCursor(0,3);
  lcd.print(remoteCameraNumber);
  Serial.print("ATEM IP Address: ");
  Serial.println(switcherIp);
  Serial.print("Remote Camera #:");
  Serial.println(remoteCameraNumber);

  delay(2000);

  XBee.write("C");
  setAll(tallyUnit[0].Color(0,0,0));

  lcd.clear();
  lcd.setCursor(0,0);
  lcd.print("0|1 2 3 4 5 6 7 8 9");
  lcd.setCursor(0,2);
  lcd.print("1|0 1 2 R   RmtCam#");
  lcd.setCursor(12,3);
  lcd.print(String(remoteCameraNumber));
}

bool haveDefinedMaxCameras = false;
void loop() {
  handleSerialConfig();
  
  AtemSwitcher.runLoop();

  if(haveDefinedMaxCameras == false) {
    // Automatically set the number of tally lights up to 12.
    numberOfTallyLights = AtemSwitcher.getTallyByIndexSources();
    if(numberOfTallyLights > MAX_TALLY_LIGHTS) {
      numberOfTallyLights = MAX_TALLY_LIGHTS;
    }
    if(numberOfTallyLights != 0) {
      haveDefinedMaxCameras = true;
    }
  }

  bool showPreviewToTalent = digitalRead(TALENT_PREVIEW_PIN);

  int talentDimmer = map(analogRead(TALENT_DIMMER_PIN), 0, 1023, 0, 255);
  int opDimmer = map(analogRead(OP_DIMMER_PIN), 0, 1023, 0, 255);

  for (uint8_t i = 0; i < numberOfTallyLights; i++) {
    setTalleyLight(i, showPreviewToTalent, talentDimmer, opDimmer);
  }
}

void setTalleyLight(int camera, bool showPreviewToTalent, int talentBrightness, int opBrightness) {
  int tally = AtemSwitcher.getTallyByIndexTallyFlags(camera);

  if(camera + 1 == remoteCameraNumber) {
    setRemoteTally(tally, showPreviewToTalent);
  }
  
  if(camera > 9) {
    switch(camera) {
      case 10:
        lcd.setCursor(2,3);
        break;
      case 11:
        lcd.setCursor(4,3);
        break;
      case 12:
        lcd.setCursor(6,3);
        break;
    }
  } else {
    lcd.setCursor(camera + camera + 2,1);
  }
  
  switch(tally) {
    case 1:
      // Live
      tallyUnit[camera].setPixelColor(0, tallyUnit[camera].Color(opBrightness,0,0));
      tallyUnit[camera].fill(tallyUnit[camera].Color(talentBrightness,0,0), 1);
      lcd.print("L");
      break;
    case 2:
      // Preview
      tallyUnit[camera].setPixelColor(0, tallyUnit[camera].Color(0,opBrightness,0));
      if(showPreviewToTalent == true) {
        tallyUnit[camera].fill(tallyUnit[camera].Color(0,talentBrightness,0), 1);
        lcd.print("P");
      } else {
        tallyUnit[camera].fill(tallyUnit[camera].Color(0,0,0), 1);
        lcd.print("p");
      }
      break;
    case 3:
      // Both
      tallyUnit[camera].setPixelColor(0, tallyUnit[camera].Color(opBrightness,0,0));
      tallyUnit[camera].fill(tallyUnit[camera].Color(talentBrightness,0,0), 1);
      lcd.print("B");
      break;
    default:
      tallyUnit[camera].clear();
      lcd.print(" ");
      break;
  }
  tallyUnit[camera].show();
}

unsigned long time_now = 0;
void setRemoteTally(int tally, bool showPreviewToTalent) {
  // Only running the XBee at 9600baud, so adding a delay to the remote communication
  // so we don't overload the serial connection.
  if(millis() > time_now + 100) {
    time_now = millis();
    
    lcd.setCursor(8,3);
    
    switch(tally) {
      case 1:
        // Live
        lcd.print("L");
        XBee.write('L');
        break;
      case 2:
        // Preview
        if(showPreviewToTalent == true) {
          lcd.print("P");
          XBee.write('T');
        } else {
          lcd.print("p");
          XBee.write('P');
        }
        break;
      case 3:
        // Both
        lcd.print("B");
        XBee.write('L');
        break;
      default:
        lcd.print(" ");
        XBee.write('C');
        break;
    }
  }
}

void setAll(uint32_t color) {
  for (uint8_t i = 0; i < numberOfTallyLights; i++) {
    tallyUnit[i].fill(color);
    tallyUnit[i].show();
  }
  statusLed.fill(color);
  statusLed.show();
}

void handleSerialConfig() {
  static byte ndx = 0;
  char endMarker = '\n';
  char rc;
  while (Serial.available() > 0) {
    rc = Serial.read();
    
    if (rc != endMarker) {
      receivedChars[ndx] = rc;
      ndx++;
      if (ndx >= numChars) {
        ndx = numChars - 1;
      }
    }
    else {
      receivedChars[ndx] = '\0'; // terminate the string
      ndx = 0;
      parseNewConfig();
    }
  }
}

void parseNewConfig() {
  boolean nextCharIsNum = false;
  int configIp[4] = { 0, 0, 0, 0 };
  int nextOctet = 0;
  char output[40];
  
  if(receivedChars[0] == 'R') {
    sprintf(output, "Remote camera set to: %u", atoi(&receivedChars[1]));
    Serial.println(output);
    EEPROM.update(12, atoi(&receivedChars[1]));
  } else {  
    for( unsigned int a = 0; a < sizeof(receivedChars); a = a + 1 )
    {
      if(a==0) {
        nextCharIsNum = true;
        continue;
      }
      if(receivedChars[a] == '.') {
        nextCharIsNum = true;
        continue;
      }
      if(nextCharIsNum == true) {
        int octet = atoi(&receivedChars[a]);
        configIp[nextOctet] = octet;
        nextOctet = nextOctet + 1;
        nextCharIsNum = false;
      }
    }
  
    switch(receivedChars[0]) {
      case 'I':
        sprintf(output, "New IP: %u.%u.%u.%u", configIp[0], configIp[1], configIp[2], configIp[3]);
        Serial.println(output);
        EEPROM.update(0, configIp[0]);
        EEPROM.update(1, configIp[1]);
        EEPROM.update(2, configIp[2]);
        EEPROM.update(3, configIp[3]);
        break;
      case 'N':
        sprintf(output, "New Netmask: %u.%u.%u.%u", configIp[0], configIp[1], configIp[2], configIp[3]);
        Serial.println(output);
        EEPROM.update(4, configIp[0]);
        EEPROM.update(5, configIp[1]);
        EEPROM.update(6, configIp[2]);
        EEPROM.update(7, configIp[3]);
        break;
      case 'A':
        sprintf(output, "New ATEM Switcher IP: %u.%u.%u.%u", configIp[0], configIp[1], configIp[2], configIp[3]);
        Serial.println(output);
        EEPROM.update(8, configIp[0]);
        EEPROM.update(9, configIp[1]);
        EEPROM.update(10, configIp[2]);
        EEPROM.update(11, configIp[3]);
        break;
      default:
        Serial.println("Unknown config parameter");
    }
  }

  Serial.println("Resetting");
  delay(1000);
//  doInit();
  reboot();
}

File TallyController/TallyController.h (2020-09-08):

#ifndef TALLYCONTROLLER
#define TALLYCONTROLLER

#include <Arduino.h>
#include <EEPROM.h>

#include <Adafruit_NeoPixel.h>
#include <ATEMmin.h>
#include <Ethernet.h>
#include <LiquidCrystal_I2C.h>
#include <SoftwareSerial.h>
#include <SPI.h>
#include <Wire.h>

byte mac[] = { 0x00, 0xAA, 0xBB, 0xCC, 0xDE, 0x04 };

#define LED_COUNT           2   // 1 for operator, 1 for talent
int numberOfTallyLights = 8;    // Sane default value (number for ATEM Television Studio)
int remoteCameraNumber = 1;     // Which camera to assign the remote tally light to.
#define MAX_TALLY_LIGHTS    12  // Maximum number of tally lights the tally controller shield supports.

// Used for configuration via serial.
const byte numChars = 16;
char receivedChars[numChars]; // an array to store the received data

// Uno test unit assignments
//#define NUMBER_OF_TALLY_LIGHTS  4
//#define XBEE_In             2
//#define XBEE_Out            3

// Mega / Controller shield pin assignments
#define CAM1  8
#define CAM2  7
#define CAM3  6
#define CAM4  5
#define CAM5  26
#define CAM6  22
#define CAM7  28
#define CAM8  24
#define CAM9  42
#define CAM10 38
#define CAM11 44
#define CAM12 40
#define OP_DIMMER_PIN       0   // Analog 0 - Global brightness pot for rear LED
#define TALENT_DIMMER_PIN   1   // Analog 1 - Global brightness pot for front LED
#define TALENT_PREVIEW_PIN  56  // Analog 2 - Toggle displaying preview indicator to talent.
#define XBEE_In             11
#define XBEE_Out            12
#define STATUS_NEOPIXEL            13

#endif

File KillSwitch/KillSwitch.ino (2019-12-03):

#include "KillSwitch.h"

ATEMmin AtemSwitcher;


void setup() {
  pinMode(4,OUTPUT);
  digitalWrite(4,HIGH);
  pinMode(10,OUTPUT);
  digitalWrite(10,HIGH);
  pinMode(KILLSWITCH_PIN, INPUT);

  randomSeed(analogRead(5));

  // Open serial communications and wait for port to open:
  Serial.begin(9600);
  while (!Serial) {
    ; // wait for serial port to connect. Needed for native USB port only
  }

  Serial.println("Initialize Ethernet:");
  Ethernet.init(10);  // Most Arduino shields
  Ethernet.begin(mac, ip);

  if (Ethernet.hardwareStatus() == EthernetNoHardware) {
    Serial.println("Ethernet shield was not found.");
    while (true) {
      delay(1);
    }
  } else if (Ethernet.linkStatus() == LinkOFF) {
    Serial.println("Ethernet cable is not connected.");
    while (true) {
      delay(1);
    }
  }
    
  // print local IP address:
  Serial.print("My IP address: ");
  Serial.println(Ethernet.localIP());
  Serial.print("Subnet Mask: ");
  Serial.println(Ethernet.subnetMask());

  AtemSwitcher.begin(switcherIp);
  AtemSwitcher.serialOutput(1);
  AtemSwitcher.connect();

  Serial.print("ATEM IP Address: ");
  Serial.println(switcherIp);
}

unsigned long time_now = 0;
void loop() {
  AtemSwitcher.runLoop();
  bool killSwitch = digitalRead(KILLSWITCH_PIN);

  if(killSwitch == true) {
    if(millis() > time_now + 250) {
      time_now = millis();
      Serial.println("Dumping.");
      AtemSwitcher.setProgramInputVideoSource(ME_TO_KILL, DUMP_TO);
      AtemSwitcher.setPreviewInputVideoSource(ME_TO_KILL, DUMP_TO);
    }
  } else {
    time_now = 0;
  }
}

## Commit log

2019-07-26 Initial commit.
    [Tally Box With Ethernet.brd, Tally Box With Ethernet.sch, Tally Box.brd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]
2019-07-26 Rename files so the Arduino IDE won't complain
    [Tally-Base-Station.ino]
2019-07-27 Initial revision of Arduino Mega shield for controller.
    [tally-controller-shield.brd, tally-controller-shield.sch]
2019-07-27 Add some additional headers, fix switch wiring.
    Add extra I2C connector that will work with a right-angle header.
    Add a neopixel header for a possible system status light.
    Wire switch to input (missed that in the schematic)
    Trim the number of headers for holding the XBee regulated breakout to make routing easier
    Add a bunch of labels to things on the top silkscreen.
    [tally-controller-shield.brd, tally-controller-shield.sch]
2019-07-28 Major rework of the shield to make a much better layout.
    - Expanded to 12 camera support out of the box
    [tally-controller-shield.brd, tally-controller-shield.sch]
2019-07-28 Some code cleanup and prep work for using the controller shield.
    Also switch to using a 20x4 LCD display to be able to fit more status data.
2019-07-29 Initial revision for a 4ch RJ45 output board for the controller, and an RJ45 breakout for the on-camera light.
    [RJ45 4ch Output.brd, RJ45 4ch Output.sch, RJ45 Breakout.brd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]
2019-07-29 Add some global descriptions to schematics.
    [RJ45 4ch Output.sch, RJ45 Breakout.sch, tally-controller-shield.sch]
2019-07-29 Standardize RS485 pinouts, update RJ45 pinouts.
    Fix pin assignments for the RS485 interconnects to standardize on pin1 = data-.
    Update the RJ45 breakouts to be mostly pin compatible with DMX over ethernet wiring standard (using pin 5/6 for V+)
    Create an XLR RS485 breakout option for wiring cameras together using 3pin DMX cables
    [RJ45 4ch Output.brd, RJ45 4ch Output.sch, RJ45 Breakout.brd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]
2019-07-29 Create XLR-M breakout.
    [XLR-M Breakout.brd, XLR-M Breakout.sch]
2019-07-29 Re-arrange components on controller shield to interfere less with the ethernet jack.
    Creat a quick power distro for the output boards.
    [Output Power Distro.brd, Output Power Distro.sch, tally-controller-shield.brd]
2019-07-29 Update RJ45 boards to use RJHSE Amphenol jacks
    [RJ45 4ch Output.brd, RJ45 4ch Output.sch, RJ45 Breakout.brd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]
2019-07-29 Add bottom silkscreen.
    [RJ45 4ch Output.brd]
2019-07-31 Add notes to schematic. Code cleanup of sketch.
    [tally-controller-shield.sch]
2019-07-31 Clean up directory names.
    [Output Power Distro.brd, Output Power Distro.sch, RJ45 4ch Output.brd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]
2019-08-01 Slim down some spacings to possibly use some 8 pin headers instead of 4x 2pin. Fix hole drill sizes.
    [Output Power Distro.brd, RJ45 4ch Output.brd, RJ45 Breakout.brd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]
2019-08-01 New design for RS485->Neopixel adapter with same width dimension as RJ45 breakout.
    [RS485 to Neopixel.brd, RS485 to Neopixel.sch, Tally Box.brd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]
2019-08-01 Update silkscreen
    [RS485 to Neopixel.brd]
2019-08-02 Add external power input to power all the external bits. Fix DRC errors that I didn't catch for some reason.
    [tally-controller-shield.brd, tally-controller-shield.sch]
2019-08-02 May as well make the VCC line from the external power thicc
    [tally-controller-shield.brd]
2019-08-07 New on-camera board sized to fit Hammond 1551H enclosures.
    New version of tally shield using some SMD components, and exposing two
    serial interfaces for possible usage.
    Remove the XLR breakouts, they were just speculative.
    [1551H-RS485 to Neopixel with RJ45.brd, 1551H-RS485 to Neopixel with RJ45.sch, XLR-F Breakout.brd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]
2019-08-08 Some more designs to fit different Hammond enclosures.
    [1591XXA-RS485 to Neopixel with RJ45.brd, 1591XXA-RS485 to Neopixel with RJ45.sch, 1591XXM-RS485 to Neopixel with RJ45.brd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]
2019-08-15 Go through and fix notation on RS485 wiring everywhere to use the standard A/B notation.
    [1551H-RS485 to Neopixel with RJ45.brd, 1551H-RS485 to Neopixel with RJ45.sch, 1591XXA-RS485 to Neopixel with RJ45.brd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]
2019-08-15 Fix the non SMD version of the controller as well.
    Also add pads for terminators at the controller.
    [tally-controller-shield.brd, tally-controller-shield.sch]
2019-08-15 Shift the RS485 drivers so they're aligned consistently
    [tally-controller-shield-smd.brd, tally-controller-shield-smd.sch]
2019-08-19 Revisions to SMD version of controller board. Create board for wireless tally. Code revisions to sketch.
    [WirelessTallyReceiver.brd, WirelessTallyReceiver.sch, tally-controller-shield-smd.brd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]
2019-08-19 Quick tweaks
    [tally-controller-shield-smd.brd]
2019-08-19 Update filename to reflect the enclosure type.
    [1593K-WirelessTallyReceiver.brd, 1593K-WirelessTallyReceiver.sch]
2019-08-19 Adjust large hole drill size. Add additional text to silkscreen.
    [1593K-WirelessTallyReceiver.brd]
2019-09-02 Revisions to boards after working with initial prototypes.
    - Update boards to use SMD components to help save on space.
    - Redesign wireless receiver to use 3.3v logic to avoid using the Xbee breakout.
    - Remove designs that aren't going to be used.
    [1551H-RS485 to Neopixel with RJ45.brd, 1551H-RS485 to Neopixel with RJ45.sch, 1591XXA-RS485 to Neopixel with RJ45.brd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]
2019-09-02 Remove old original prototype.
    [Tally Box.brd, Tally Box.sch]
2019-11-27 Tweaks to controller and wireless receiver after field test.
2019-11-28 Minor tweaks for ethernet mega.
    [tally-controller-shield-smd.brd]
2019-11-28 Create Arduino sketch for ATEM kill switch.
2019-12-03 Update kill switch to send constant commands when killswitch engaged.
    To require manual intervention to recover.
2019-12-13 Add guards to header. Update check for max cameras to only run once.
2019-12-29 Add decoupling caps to shield.
    Remove non-SMD version of shield (no-longer being worked on).
    [tally-controller-shield-smd.brd, tally-controller-shield-smd.sch, tally-controller-shield.brd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]
2019-12-30 Add example build images of tally system.
    [1593K-WirelessTallyReceiver.brd, 1593K-WirelessTallyReceiver.sch]
2020-01-01 Add decoupling caps
    [1551H-RS485 to Neopixel with RJ45.brd, 1551H-RS485 to Neopixel with RJ45.sch, 1593K-WirelessTallyReceiver-XBee.brd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]
2020-01-05 Fix issue with controller thinking there are 0 cameras.`
    [TallyController.ino]
2020-01-13 Add optional AREF jumper. Remove unused nets.
    [tally-controller-shield-smd.brd, tally-controller-shield-smd.sch]
2020-05-03 Add BOM information for tally controller.
2020-05-03 Update buck converter link.
2020-09-08 Add ability to configure which camera has the remote/wireless tally light.
2020-09-08 Add note for configuring remote camera #

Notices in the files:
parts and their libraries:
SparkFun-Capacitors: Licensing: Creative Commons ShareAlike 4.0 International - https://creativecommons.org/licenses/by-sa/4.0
